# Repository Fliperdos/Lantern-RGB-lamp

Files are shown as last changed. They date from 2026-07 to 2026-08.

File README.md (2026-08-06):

# Lantern-RGB-lamp
RGB lamp inspired by the minecraft lantern
parts: 
Esp32 c3 supermini (clone from china bought for cheap)
ws2812b rgb led matrix 5x5 version
ttp223 touch button module used for brightness controll/turning off
the whole lantern was printed with my a1 mini, no ams.
its separated into 3 main sections - the base and top wich are  were printed black and 4 pillars wich were printed brown. the pillars should have a fit thats on the tighter side both to the top and the base.

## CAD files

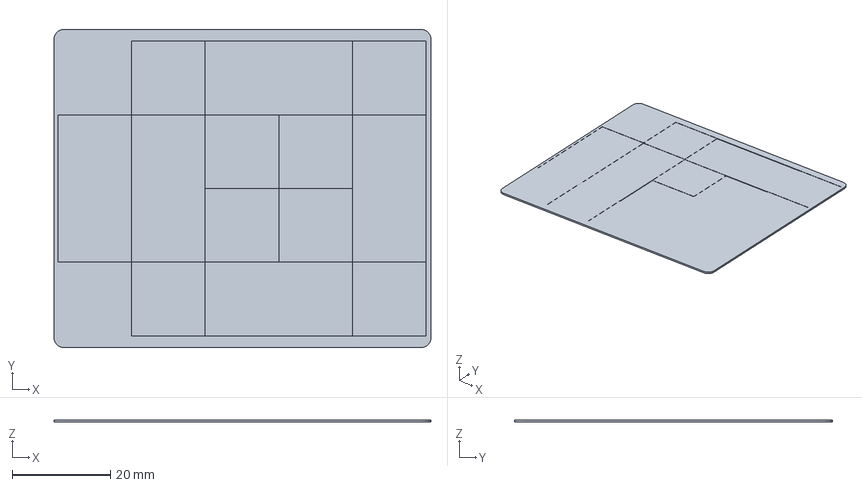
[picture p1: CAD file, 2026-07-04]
prints/windows.3mf
76.8 x 64.8 x 0.48 mm

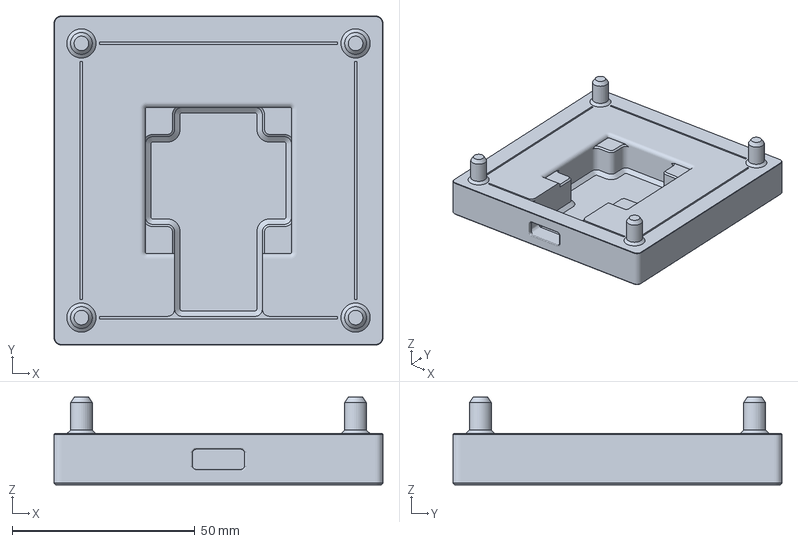
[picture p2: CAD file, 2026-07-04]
prints/base.3mf
90.0 x 90.0 x 24.0 mm

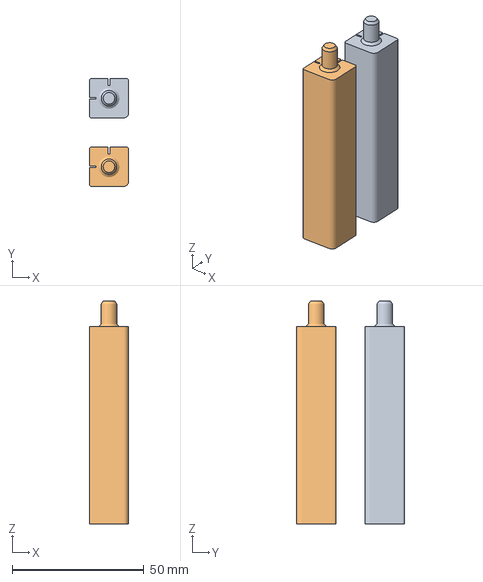
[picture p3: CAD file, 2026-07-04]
prints/pillars.3mf
15.0 x 41.0 x 84.7 mm
pillars.stl_4 x 2

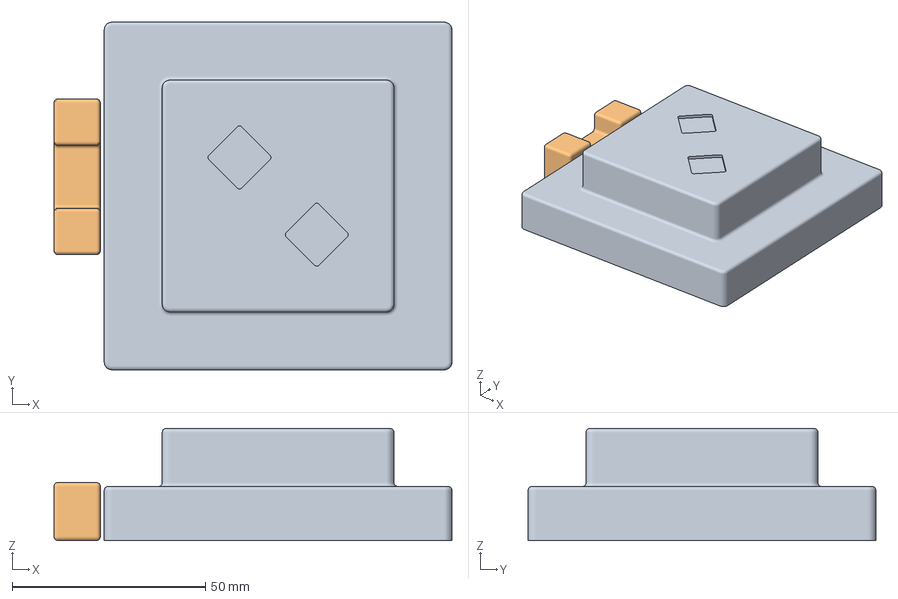
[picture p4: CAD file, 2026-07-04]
prints/top.3mf
103.0 x 90.0 x 29.0 mm
top.stl_1
top.stl_2

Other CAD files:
prints/window.stl
prints/base.stl
prints/pillars.stl
prints/top.stl

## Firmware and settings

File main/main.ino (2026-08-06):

#include <WiFi.h>
#include <ESPmDNS.h>
#include <FastLED.h>
#if __has_include("wifi_secrets.h")
#include "wifi_secrets.h"
#else
#include "wifi_secrets.example.h"
#endif

#define NUM_LEDS  25
#define DATA_PIN  21
#define PIN_BTN   4

NetworkServer server(80);
CRGB leds[NUM_LEDS];

int  brightnessLevel = 3;
int  curR = 255, curG = 255, curB = 255;
const uint8_t LEVELS[6] = {0, 51, 102, 153, 204, 255};

void applyBrightness() {
  FastLED.setBrightness(LEVELS[brightnessLevel]);
  FastLED.show();
}

void sendOK(NetworkClient &client) {
  client.println("HTTP/1.1 200 OK");
  client.println("Content-Length: 0");
  client.println("Connection: close");
  client.println();
}

void sendState(NetworkClient &client) {
  String json = "{\"brightness\":" + String(LEVELS[brightnessLevel]) +
                ",\"level\":"      + String(brightnessLevel) +
                ",\"r\":"          + String(curR) +
                ",\"g\":"          + String(curG) +
                ",\"b\":"          + String(curB) + "}";
  client.println("HTTP/1.1 200 OK");
  client.println("Content-Type: application/json");
  client.println("Connection: close");
  client.println();
  client.print(json);
}

unsigned long lastBtnTime = 0;
bool lastBtnState = LOW;
const unsigned long DEBOUNCE = 300;

void handleTouch() {
  unsigned long now = millis();
  bool btnState = digitalRead(PIN_BTN);

  if (btnState == HIGH && lastBtnState == LOW && now - lastBtnTime > DEBOUNCE) {
    lastBtnTime = now;
    brightnessLevel = (brightnessLevel + 1) % 6;
    applyBrightness();
  }
  lastBtnState = btnState;
}

void connectWiFi() {
  WiFi.mode(WIFI_STA);
  WiFi.setTxPower(WIFI_POWER_8_5dBm);   // cuts radio current spikes, prevents dips on weak supplies
  WiFi.begin(WIFI_SSID, WIFI_PASSWORD);

  unsigned long start = millis();
  while (WiFi.status() != WL_CONNECTED) {
    handleTouch();       // keeps button responsive during connect, unlike blocking delay-only loop
    delay(20);
    if (millis() - start > 15000) {   // avoid infinite hang on bad network
      WiFi.disconnect();
      delay(200);
      WiFi.begin(WIFI_SSID, WIFI_PASSWORD);
      start = millis();
    }
  }
}

void setup() {
  pinMode(PIN_BTN, INPUT);

  FastLED.addLeds<WS2812B, DATA_PIN, GRB>(leds, NUM_LEDS);
  FastLED.setMaxPowerInVoltsAndMilliamps(5, 1000); // caps LED draw, prevents brownout on power-only USB-C sources
  fill_solid(leds, NUM_LEDS, CRGB(curR, curG, curB));
  applyBrightness();

  connectWiFi();
  server.begin();
  MDNS.begin("lantern");
}

void loop() {
  handleTouch();

  NetworkClient client = server.accept();
  if (!client) return;

  String currentLine = "";
  unsigned long timeout = millis();

  while (client.connected() && millis() - timeout < 800) {
    if (!client.available()) { handleTouch(); continue; }
    timeout = millis();
    char c = client.read();

    if (c == '\n') {
      if (currentLine.length() == 0) {
        client.println("HTTP/1.1 200 OK");
        client.println("Content-type:text/html");
        client.println("Connection: close");
        client.println();
        client.print(R"rawhtml(<!DOCTYPE html>
<html>
<head>
<meta charset="UTF-8">
<meta name="viewport" content="width=device-width,initial-scale=1">
<title>Lantern</title>
<style>
*{box-sizing:border-box;margin:0;padding:0}
body{background:#111;font-family:sans-serif;display:flex;justify-content:center;padding:1.5rem 1rem}
.wrap{width:100%;max-width:380px;display:flex;flex-direction:column;gap:1.25rem}
.card{background:#1e1e1e;border:1px solid #2e2e2e;border-radius:14px;padding:1rem 1.25rem}
.row{display:flex;align-items:center;justify-content:space-between}
.sec-title{font-size:13px;font-weight:500;color:#888;margin-bottom:.75rem}
.toggle-track{width:52px;height:28px;border-radius:14px;background:#333;position:relative;cursor:pointer;border:none;outline:none;flex-shrink:0;transition:background .2s}
.toggle-track.on{background:#2a9d5c}
.toggle-thumb{width:22px;height:22px;border-radius:50%;background:#fff;position:absolute;top:3px;left:3px;transition:left .2s;box-shadow:0 1px 3px rgba(0,0,0,.4)}
.toggle-track.on .toggle-thumb{left:27px}
.device-name{font-size:16px;font-weight:500;color:#eee}
.wheel-wrap{display:flex;justify-content:center;padding:.5rem 0}
canvas{border-radius:50%;cursor:crosshair;display:block;touch-action:none}
.preview{width:100%;height:44px;border-radius:10px;border:1px solid #2e2e2e;margin-top:.75rem;transition:background .1s}
.presets{display:grid;grid-template-columns:repeat(5,1fr);gap:8px;margin-top:.25rem}
.preset-btn{border:1px solid #2e2e2e;border-radius:10px;padding:8px 4px;cursor:pointer;background:#1e1e1e;display:flex;flex-direction:column;align-items:center;gap:5px}
.preset-btn:active{transform:scale(.95)}
.preset-btn.active{border:2px solid #aaa}
.preset-dot{width:16px;height:16px;border-radius:50%}
.preset-label{font-size:10px;color:#888;text-align:center;line-height:1.3}
.bright-ctrl{display:flex;flex-direction:column;align-items:center;gap:.5rem}
.bright-btn{width:100%;padding:.75rem;background:#2a2a2a;border:1px solid #2e2e2e;border-radius:10px;color:#eee;font-size:20px;cursor:pointer;transition:background .15s}
.bright-btn:active{background:#3a3a3a}
.bright-btn:disabled{opacity:.25;cursor:default}
.bright-display{font-size:15px;color:#eee;font-weight:500}
.bright-sub{font-size:11px;color:#555}
</style>
</head>
<body>
<div class="wrap">
  <div class="card">
    <div class="row">
      <span class="device-name">Lantern</span>
      <button class="toggle-track" id="toggle" onclick="togglePower()">
        <div class="toggle-thumb"></div>
      </button>
    </div>
  </div>
  <div class="card">
    <div class="sec-title">Brightness</div>
    <div class="bright-ctrl">
      <button class="bright-btn" id="btn-up" onclick="stepBrightness(1)">&#9650;</button>
      <div style="text-align:center">
        <div class="bright-display" id="blevel">3 / 5</div>
        <div class="bright-sub" id="bpct">60%</div>
      </div>
      <button class="bright-btn" id="btn-down" onclick="stepBrightness(-1)">&#9660;</button>
    </div>
  </div>
  <div class="card">
    <div class="sec-title">Color</div>
    <div class="wheel-wrap">
      <canvas id="wheel" width="220" height="220"></canvas>
    </div>
    <div class="preview" id="preview" style="background:rgb(255,255,255)"></div>
  </div>
  <div class="card">
    <div class="sec-title">Temperature</div>
    <div class="presets" id="presets"></div>
  </div>
</div>
<script>
const PRESETS=[
  {label:'Candle',K:'1800K',r:255,g:147,b:41},
  {label:'Warm',K:'2700K',r:255,g:197,b:143},
  {label:'Neutral',K:'4000K',r:255,g:228,b:205},
  {label:'Cool',K:'5500K',r:220,g:229,b:255},
  {label:'Day',K:'6500K',r:201,g:218,b:255}
];
const LEVELS=[0,51,102,153,204,255];
let dragging=false,pendingColor=null,sending=false;
let curLevel=3;

function updateBrightUI(level){
  curLevel=level;
  document.getElementById('blevel').textContent=(level==0?'Off':level+' / 5');
  document.getElementById('bpct').textContent=Math.round(LEVELS[level]/255*100)+'%';
  document.getElementById('btn-up').disabled=level>=5;
  document.getElementById('btn-down').disabled=level<=0;
  document.getElementById('toggle').classList.toggle('on',level>0);
}

function pollState(){
  fetch('/state').then(r=>r.json()).then(s=>{
    updateBrightUI(s.level);
    document.getElementById('preview').style.background='rgb('+s.r+','+s.g+','+s.b+')';
  }).catch(()=>{});
}
setInterval(pollState,1500);
pollState();

function togglePower(){
  const on=document.getElementById('toggle').classList.contains('on');
  fetch(on?'/off':'/on').catch(()=>{});
}

function stepBrightness(dir){
  const next=Math.min(5,Math.max(0,curLevel+dir));
  if(next===curLevel)return;
  updateBrightUI(next);
  fetch('/brightness?v='+LEVELS[next]).catch(()=>{});
}

function sendColor(r,g,b){
  if(sending){pendingColor={r,g,b};return;}
  sending=true;
  fetch('/color?r='+r+'&g='+g+'&b='+b)
    .catch(()=>{})
    .finally(()=>{
      sending=false;
      if(pendingColor){const c=pendingColor;pendingColor=null;sendColor(c.r,c.g,c.b);}
    });
}

function setPreview(r,g,b){
  document.getElementById('preview').style.background='rgb('+r+','+g+','+b+')';
}

function buildPresets(){
  const c=document.getElementById('presets');
  PRESETS.forEach(p=>{
    const b=document.createElement('button');
    b.className='preset-btn';
    b.innerHTML='<div class="preset-dot" style="background:rgb('+p.r+','+p.g+','+p.b+')"></div><span class="preset-label">'+p.label+'<br>'+p.K+'</span>';
    b.onclick=()=>{
      setPreview(p.r,p.g,p.b);
      document.querySelectorAll('.preset-btn').forEach(x=>x.classList.remove('active'));
      b.classList.add('active');
      sendColor(p.r,p.g,p.b);
    };
    c.appendChild(b);
  });
}

function drawWheel(){
  const cv=document.getElementById('wheel');
  const ctx=cv.getContext('2d');
  const cx=110,cy=110,r=106;
  const conic=ctx.createConicGradient(-Math.PI/2,cx,cy);
  for(let i=0;i<=360;i++) conic.addColorStop(i/360,'hsl('+i+',100%,50%)');
  ctx.beginPath();ctx.arc(cx,cy,r,0,Math.PI*2);
  ctx.fillStyle=conic;ctx.fill();
  const radial=ctx.createRadialGradient(cx,cy,0,cx,cy,r);
  radial.addColorStop(0,'rgba(255,255,255,1)');
  radial.addColorStop(1,'rgba(255,255,255,0)');
  ctx.beginPath();ctx.arc(cx,cy,r,0,Math.PI*2);
  ctx.fillStyle=radial;ctx.fill();
}

function pickColor(e){
  const cv=document.getElementById('wheel');
  const rect=cv.getBoundingClientRect();
  const touch=e.touches?e.touches[0]:e;
  const x=touch.clientX-rect.left,y=touch.clientY-rect.top;
  const scale=cv.width/rect.width;
  const d=cv.getContext('2d').getImageData(Math.round(x*scale),Math.round(y*scale),1,1).data;
  if(d[3]<10)return;
  setPreview(d[0],d[1],d[2]);
  document.querySelectorAll('.preset-btn').forEach(x=>x.classList.remove('active'));
  sendColor(d[0],d[1],d[2]);
}

const cv=document.getElementById('wheel');
cv.addEventListener('mousedown',e=>{dragging=true;pickColor(e);});
cv.addEventListener('mousemove',e=>{if(dragging)pickColor(e);});
document.addEventListener('mouseup',()=>dragging=false);
cv.addEventListener('touchstart',e=>{e.preventDefault();pickColor(e);},{passive:false});
cv.addEventListener('touchmove',e=>{e.preventDefault();pickColor(e);},{passive:false});
drawWheel();buildPresets();
</script>
</body>
</html>)rawhtml");
        break;
      }
      else currentLine = "";
    }
    else if (c != '\r') {
      currentLine += c;

      if (currentLine.endsWith("/on")) {
        if (brightnessLevel == 0) brightnessLevel = 3;
        applyBrightness();
        sendOK(client); break;
      }
      if (currentLine.endsWith("/off")) {
        brightnessLevel = 0;
        applyBrightness();
        sendOK(client); break;
      }
      if (currentLine.indexOf("/brightness?v=") >= 0 && currentLine.endsWith(" HTTP/1.1")) {
        int val = currentLine.substring(currentLine.indexOf("?v=") + 3).toInt();
        int best = 0;
        for (int i = 1; i < 6; i++)
          if (abs(val - LEVELS[i]) < abs(val - LEVELS[best])) best = i;
        brightnessLevel = best;
        applyBrightness();
        sendOK(client); break;
      }
      if (currentLine.indexOf("/color?r=") >= 0 && currentLine.endsWith(" HTTP/1.1")) {
        int ampG = currentLine.indexOf("&g=");
        int ampB = currentLine.indexOf("&b=");
        int spH  = currentLine.indexOf(" HTTP/1.1");
        curR = currentLine.substring(currentLine.indexOf("r=") + 2, ampG).toInt();
        curG = currentLine.substring(ampG + 3, ampB).toInt();
        curB = currentLine.substring(ampB + 3, spH).toInt();
        fill_solid(leds, NUM_LEDS, CRGB(curR, curG, curB));
        FastLED.show();
        sendOK(client); break;
      }
      if (currentLine.indexOf("/state") >= 0 && currentLine.endsWith(" HTTP/1.1")) {
        sendState(client); break;
      }
    }
  }

  client.stop();
}

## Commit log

2026-06-11 Add files via upload
    made lantern v4. its really small, ill make a bigger version some way down the road. started calibrating filaments.
    things to do:
    add a small tolerance to holes for a tight fit
    add a touch sensor + cad a hole for the sensors cables
    make a bigger lantern v5
    [5x5led.step, 8x8led.step, legs.3mf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]
2026-06-13 added better off mode handling
    turns off led matrix with 0 brightness, not setting the color to 0,0,0
2026-06-15 made bigger parts, last were too small.
    problems:
    printing top layers after a lot of infill, ironing turns out messed up
    [base_v2.stl, bottom.3mf, bottom.stl]
2026-06-28 remade code, lantern v6
    updated code to work with 2 touch buttons for brightness - deleted the brightness slider on the web page and made it into 5 levels of brightness. Switch is now set to off when brightness is 0
    made lantern v6 - betters pegs, printing to find the best tolerance, yet to make windows in cad
    [base.3mf, base.stl, pillars - +0.05 tol_.stl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]
2026-07-04 updated code and print files
    code - discarded one touch button, now theres only one which cycles through the brightness levels
    print files - optimized printing settings, made windows
    after this i soldered everything together
    [base.3mf, base.stl, pillars.3mf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]
